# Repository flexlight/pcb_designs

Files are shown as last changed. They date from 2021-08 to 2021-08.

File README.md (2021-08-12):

# Here you will find PCB Designs for your Own FlexLight

## Software used

We create all our PCB designs using EasyEDA to enable fast and easy ordering of PCBs from jlcpcb.
Just import the project files and tinker away.
For even easier ordering you can also just download the Gerber, BOM and CPL files that are available in the gerber directory of each PCB folder.

## PCB Designs available
### LED PCB:

LED PCB

The led PCB holds 8 argb ws2813-mini LED's for illumination and is soldered to each one of the main PCBs via the 5 connecting plates in the lower middle.
it measures 140 x 5,4 in mm, we wanted to have this one as thin as possible to not add unneccesary thickness to the flexlight case.

The gerber files of this PCB are pre-panelized to hold 6 PCB's in one production run. This was needed for JLCPCB's SMT assembly since their minimum PCB size is 20mm x 20mm and our LED PCB width is just 5.4mm, that way if you order with the pre-made gerbers at jlcpcb you will end up with a minimum order of 30 LED PCBs which should be enough for 10 triangle shaped flexlight nodes

### Inteconnect PCB:

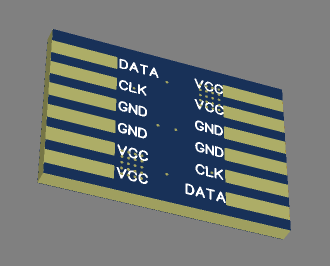
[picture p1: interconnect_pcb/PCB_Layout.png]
Inteconnect PCB


The Interconnect PCB is used to connect 2 nodes together, it is probably the most simple and most cheap PCB of our project, dosnt hold any components, just order and use.
We use 2 contacts for 24v and GND to be able to deliver up to 6A to the Flexlight array and power up to 60 nodes safely from a single power source.

### Mainboard BLANK PCB:

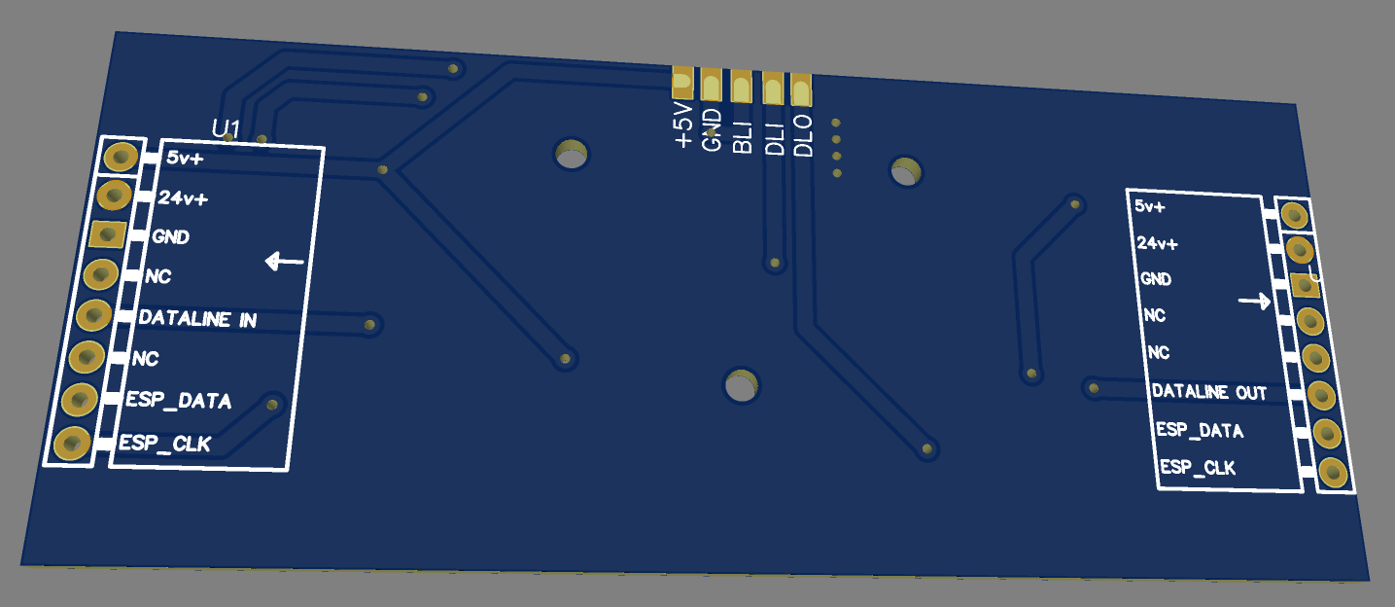
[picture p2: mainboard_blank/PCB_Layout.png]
Mainboard BLANK PCB


Mainboard BLANK PCB is one of 3 similar board that are providing connectivity between all 3 LED PCBs, the microcontroller, voltage and inter-node connectivity.

WARNING: this one is still work in progress, currently known limitation: the backup line feature of the ws2813 mini leds is only working within a single PCB, a future revision might fix this to make sure all 3 LED PCBs share one common backup signal input line.

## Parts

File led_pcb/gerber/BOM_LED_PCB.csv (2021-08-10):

ID | Name | Designator | Footprint | Quantity | Manufacturer Part | Manufacturer | Supplier | Supplier Part | Price | JLCPCB Part Class
1 | Castellated_Pad x1 | +5V,GND,BI,DI,DO | CASTELLATED_PAD_2 | 5
2 | WS2813-MINI(WS2813-3535) | LED1,LED2,LED3,LED4,LED5,LED6,LED7,LED8 | LED-SMD_L3.5-W3.5-P1.10-BR | 8 | WS2813-Mini(WS2813-3535) | Worldsemi | LCSC | C189639 | 0.161 | Extended Part
3 | 100nF | C1,C2,C3,C4,C5,C6,C7,C8 | C0402_NEW | 8 | CL05B104KO5NNNC | SAMSUNG | LCSC | C1525 | 0.001 | Basic Part
4 | 200 | R1,R2,R3,R4,R5,R6,R7,R8 | R0402 | 8 | 0402WGF2000TCE | UniOhm | LCSC | C25087 | 0.001 | Basic Part

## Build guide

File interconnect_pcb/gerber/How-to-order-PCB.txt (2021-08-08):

How to Order PCB

Please refer to:
https://docs.easyeda.com/en/PCB/Order-PCB

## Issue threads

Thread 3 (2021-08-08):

Create Main PCB to hold an ESP32 for all the logic level work

psych0d0g, 2021-08-08:
We need a main PCB that has the esp32 as a brain for each flexlight module. it needs a connector for the connecting PCB on the bottom and solder pads to solder on a LED PCB to the top.

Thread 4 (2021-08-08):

Create Main PCB for Power Supply and distribution inside of a flexlight module

psych0d0g, 2021-08-08:
We need a main PCB that has the current converters as a PSU for each flexlight module. it needs a connector for the connecting PCB on the bottom and solder pads to solder on a LED PCB to the top.

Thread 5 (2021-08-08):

Create a blank PCB for interconnection inside of Flexlight module

psych0d0g, 2021-08-08:
We need a main PCB that holds a connector on the downside, aswell as has some solder points to solder on a LED PCB to the top.
it needs to be connected to the ESP and the PSU PCBs

psych0d0g, 2021-08-12:
current revision should be sufficient for our prototype.

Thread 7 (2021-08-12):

LED PCB Missing a pin for continuous backup dataline

psych0d0g, 2021-08-12:
To Enable the backup dataline feature of the used ws2813 mini argb leds the PCB needs an additional pin connection to the corresponding doughter board,
namely the Dataline IN of the last LED needs to be broken out to the daughter board aswell, so the next daughterboard / LED combo can tap into it using the backupline pin

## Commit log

2021-08-08 add LED PCB Design files for EasyEDA and Gerbers
    [Gerber_BoardOutline.GKO, Gerber_BottomLayer.GBL, Gerber_BottomSolderMaskLayer.GBS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]
2021-08-10 Include resistor and Capacitor
2021-08-10 add current gerbers panelized
    [BOM_LED_PCB.csv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]
2021-08-10 add interconnecting pcb schematics
    [Gerber_BoardOutline.GKO, Gerber_BottomLayer.GBL, Gerber_BottomSilkLayer.GBO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]
2021-08-12 current state of the first mainboard
